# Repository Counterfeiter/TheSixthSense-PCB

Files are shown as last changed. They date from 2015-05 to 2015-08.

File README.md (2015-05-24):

TheSixthSense Schematic and PCB Files
==============

License
--------------
OSH - GPLv2

Software
--------------
Free Version of CADSoft Eagle v6 (.1)

Included
--------------
- versions history
- schematic
- PCB design
- Images

Schematic:
--------------
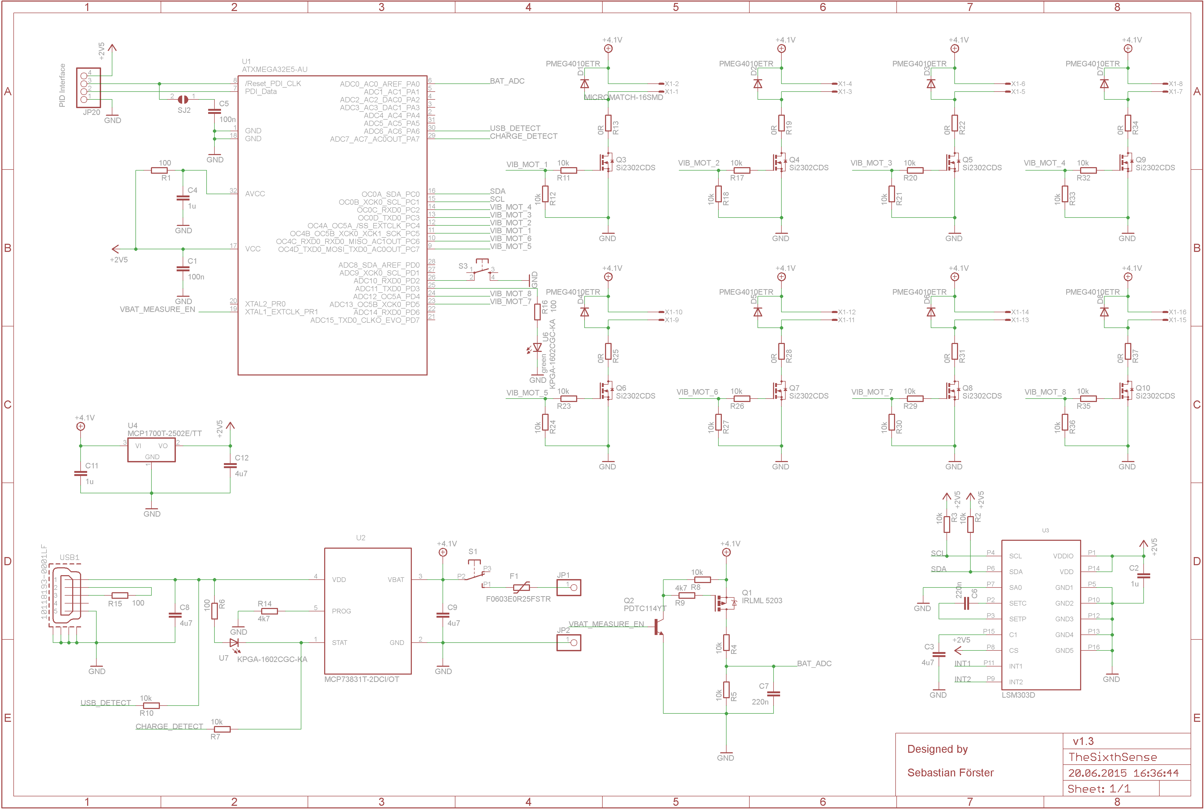
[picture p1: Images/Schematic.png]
Schematic


Board design:
--------------
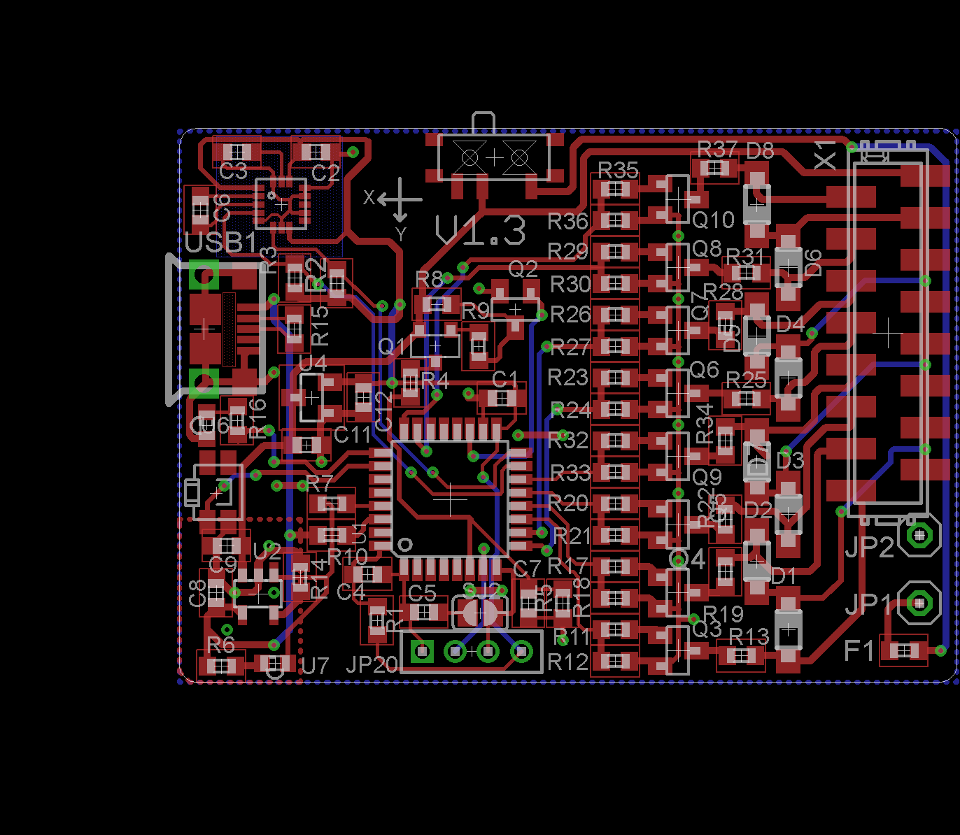
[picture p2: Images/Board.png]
Board


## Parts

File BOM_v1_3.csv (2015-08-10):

TheSixthSense v1.3 BOM; date 10.08.2015
Quantity | Value | Mouser Part Number | Device | Part
1 | 10-XX | 688-SKSCLAE010 | 10-XX | S3
2 | PINHD-1X1 | 538-22-28-8020 | PINHD-1X1 | JP1, JP2
8 | 0R | 667-ERJ-3GEY0R00V | R-EU_R0603 | R13, R19, R22, R25, R28, R31, R34, R37
3 | 1u | 80-C0603C105K8P | C-EUC0603 | C2, C4, C11
2 | 4k7 | 667-ERJ-3EKF4701V | R-EU_R0603 | R9, R14
4 | 4u7 | 80-C0603C475K8P | C-EUC0603 | C3, C8, C9, C12
23 | 10k | 667-ERJ-3EKF1002V | R-EU_R0603 | R2, R3, R4, R5, R7, R8, R10, R11, R12, R17, R18, R20, R21, R23, R24, R26, R27, R29, R30, R32, R33, R35, R36
4 | 100R | 667-ERJ-3EKF1000V | R-EU_R0603 | R1, R6, R15, R16
2 | 100n | 80-C0603C104K4R | C-EUC0603 | C1, C5
2 | 220n | 80-C0603X224K4R | C-EUC0603 | C6, C7
1 | 10118193-0001LF | 649-10118193-0001LF | MOLEX-47346-0001 | USB1
1 | ALPSSSSS811101 | 688-SSSS811101 | ALPSSSSS811101 | S1
1 | ATXMEGA32E5-AU | 556-ATXMEGA32E5-AU | AVR_XMEGA_E | U1
1 | F0603E0R25FSTR | 581-F0603E0R25FSTR | PMS1812 | F1
1 | IRLML 5203 | 942-IRLML5203TRPBF | IRLML5203 | Q1
2 | KPGA-1602CGC-KA | 859-LTST-S270KGKT | APA1606SURCK | U6, U7
1 | LSM303D | 511-LSM303DTR | LSM303D | U3
1 | MCP1700T-2502E/TT | 579-MCP1700T2502E/TT | XC6206P332MR | U4
1 | MCP73831 | 579-MCP73831T-2ATIOT | MCP73831 | U2
1 | MICROMATCH-16SMD | 571-8-2178711-6 | MICROMATCH-16SMD | X1
1 | PDTC114YT | 771-PDTC114YTT/R | BC848ALT1SMD | Q2
8 | PMEG4010ETR | 771-PMEG4010ETR115 | MBR0520LT | D1, D2, D3, D4, D5, D6, D7, D8
8 | Si2302CDS | 781-SI2302CDS-E3 | BSS123 | Q3, Q4, Q5, Q6, Q7, Q8, Q9, Q10
1 | MICROMATCH-16SMD-Plug | 571-8-215083-6

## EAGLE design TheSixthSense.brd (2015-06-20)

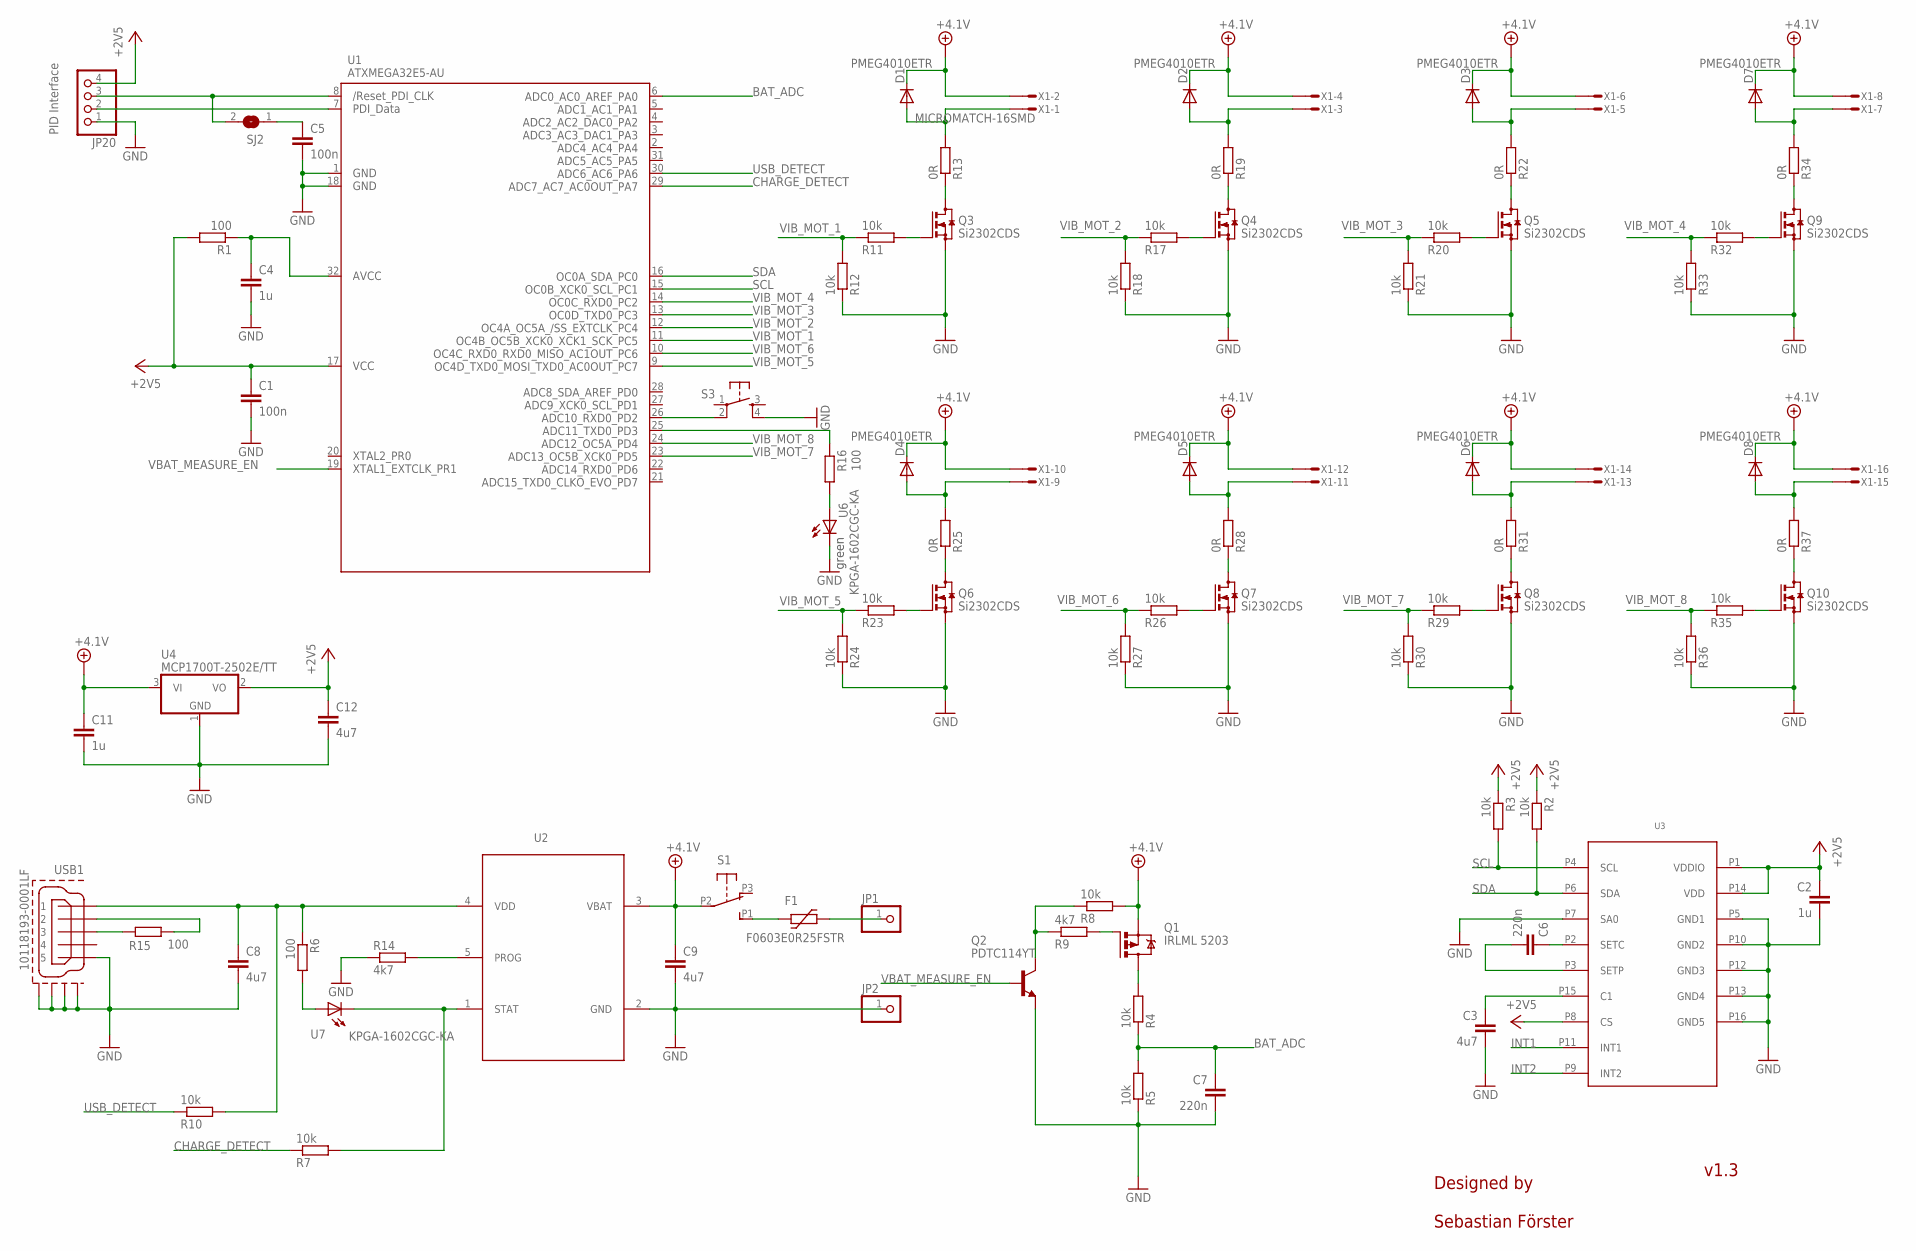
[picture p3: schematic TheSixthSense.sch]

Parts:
C1, C5: 100n; C0603
C2, C4, C11: 1u; C0603
C3, C8, C9, C12: 4u7; C0603
C6, C7: 220n; C0603
D1, D2, D3, D4, D5, D6, D7, D8: PMEG4010ETR; SOD123
F1: F0603E0R25FSTR; R0603
JP1, JP2: PINHD-1X1; 1X01
JP20: PINHD-1X4_2.00; 1X04M
Q1: IRLML 5203; MICRO3
Q2: PDTC114YT; SOT23
Q3, Q4, Q5, Q6, Q7, Q8, Q9, Q10: Si2302CDS; SOT23
R1, R6, R15, R16: 100; R0603
R2, R3, R4, R5, R7, R8, R10, R11, R12, R17, R18, R20, R21, R23, R24, R26, R27, R29, R30, R32, R33, R35, R36: 10k; R0603
R9, R14: 4k7; R0603
R13, R19, R22, R25, R28, R31, R34, R37: 0R; R0603
S1: ALPSSSSS811101; SSSS811101
S3: 10-XX; SKSCLAE010
SJ2: SJ
U1: ATXMEGA32E5-AU; TQFP32-08
U2: MCP73831; SOT23-5L
U3: LSM303D; LGA3X3_16L
U4: MCP1700T-2502E/TT; SOT23
U6, U7: KPGA-1602CGC-KA; CHIP-LED0603
USB1: 10118193-0001LF; MOLEX-47364-0001
X1: MICROMATCH-16SMD

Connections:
+3V3: C1.1, C2.1, C12.1, JP20.4, R1.2, R2.1, R3.1, U1.17 (VCC3), U3.P1 (VDDIO), U3.P8 (CS), U3.P14 (VDD), U4.2 (VO)
+4.1V: C9.1, C11.1, D1.C, D2.C, D3.C, D4.C, D5.C, D6.C, D7.C, D8.C, Q1.2 (S), R8.2, S1.P2, U2.3 (VBAT), U4.3 (VI), X1.1, X1.3, X1.5, X1.7, X1.9, X1.11, X1.13, X1.15
BAT_ADC: C7.1, R4.1, R5.2, U1.6 (PA0)
CHARGE_DETECT: R7.1, U1.29 (PA7)
GND: C1.2, C2.2, C3.2, C4.2, C5.2, C7.2, C8.2, C9.2, C11.2, C12.2, JP2.1, JP20.1, Q2.2 (E), Q3.2 (S), Q4.2 (S), Q5.2 (S), Q6.2 (S), Q7.2 (S), Q8.2 (S), Q9.2 (S), Q10.2 (S), R5.1, R12.1, R14.1, R18.1, R21.1, R24.1, R27.1, R30.1, R33.1, R36.1, S3.4 (S1), U1.1 (GND1), U1.18 (GND2), U2.2 (GND), U3.P5 (GND1), U3.P7 (SA0), U3.P10 (GND2), U3.P12 (GND3), U3.P13 (GND4), U3.P16 (GND5), U4.1 (GND), U6.C, USB1.5, USB1.GND1, USB1.GND2, USB1.GND3, USB1.GND4
GPS_ENABLE: Q2.3 (C), R8.1, R9.1
INT1: U3.P11 (INT1)
INT2: U3.P9 (INT2)
unnamed: C6.2, U3.P3 (SETP)
unnamed: Q1.3 (D), R4.2
unnamed: C3.1, U3.P15 (C1)
unnamed: C6.1, U3.P2 (SETC)
unnamed: F1.1, S1.P1 (S)
unnamed: R6.2, U7.A
unnamed: C8.1, R6.1, R10.2, U2.4 (VDD), USB1.1
unnamed: C5.1, SJ2.1
unnamed: C4.1, R1.1, U1.32 (AVCC)
unnamed: JP20.3, SJ2.2, U1.8 (RESET)
unnamed: JP20.2, U1.7 (PDI_DATA)
unnamed: R14.2, U2.5 (PROG)
unnamed: R15.1, USB1.3
unnamed: Q1.1 (G), R9.2
unnamed: Q3.1 (G), R11.2
unnamed: Q3.3 (D), R13.1
unnamed: D1.A, R13.2, X1.16
unnamed: R15.2, USB1.2
unnamed: Q4.1 (G), R17.2
unnamed: Q4.3 (D), R19.1
unnamed: D2.A, R19.2, X1.14
unnamed: Q5.1 (G), R20.2
unnamed: Q5.3 (D), R22.1
unnamed: D3.A, R22.2, X1.12
unnamed: Q6.1 (G), R23.2
unnamed: R16.2, U6.A
unnamed: Q6.3 (D), R25.1
unnamed: D4.A, R25.2, X1.8
unnamed: Q7.1 (G), R26.2
unnamed: Q7.3 (D), R28.1
unnamed: D5.A, R28.2, X1.6
unnamed: Q8.1 (G), R29.2
unnamed: Q8.3 (D), R31.1
unnamed: D6.A, R31.2, X1.4
unnamed: F1.2, JP1.1
unnamed: S3.2 (P1), U1.26 (PD2)
unnamed: R16.1, U1.25 (PD3)
unnamed: Q9.1 (G), R32.2
unnamed: Q9.3 (D), R34.1
unnamed: D7.A, R34.2, X1.10
unnamed: Q10.1 (G), R35.2
unnamed: Q10.3 (D), R37.1
unnamed: D8.A, R37.2, X1.2
NNNN: R7.2, U2.1 (STAT), U7.C
SCL: R3.2, U1.15 (PC1), U3.P4 (SCL)
SDA: R2.2, U1.16 (PC0), U3.P6 (SDA)
USB_DETECT: R10.1, U1.30 (PA6)
VBAT_MEASURE_EN: Q2.1 (B), U1.19 (PR1)
VIB_MOT_1: R11.1, R12.2, U1.11 (PC5)
VIB_MOT_2: R17.1, R18.2, U1.12 (PC4)
VIB_MOT_3: R20.1, R21.2, U1.13 (PC3)
VIB_MOT_4: R32.1, R33.2, U1.14 (PC2)
VIB_MOT_5: R23.1, R24.2, U1.9 (PC7)
VIB_MOT_6: R26.1, R27.2, U1.10 (PC6)
VIB_MOT_7: R29.1, R30.2, U1.23 (PD5)
VIB_MOT_8: R35.1, R36.2, U1.24 (PD4)

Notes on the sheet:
PID Interface
Designed by
Sebastian Förster
green
v1.3

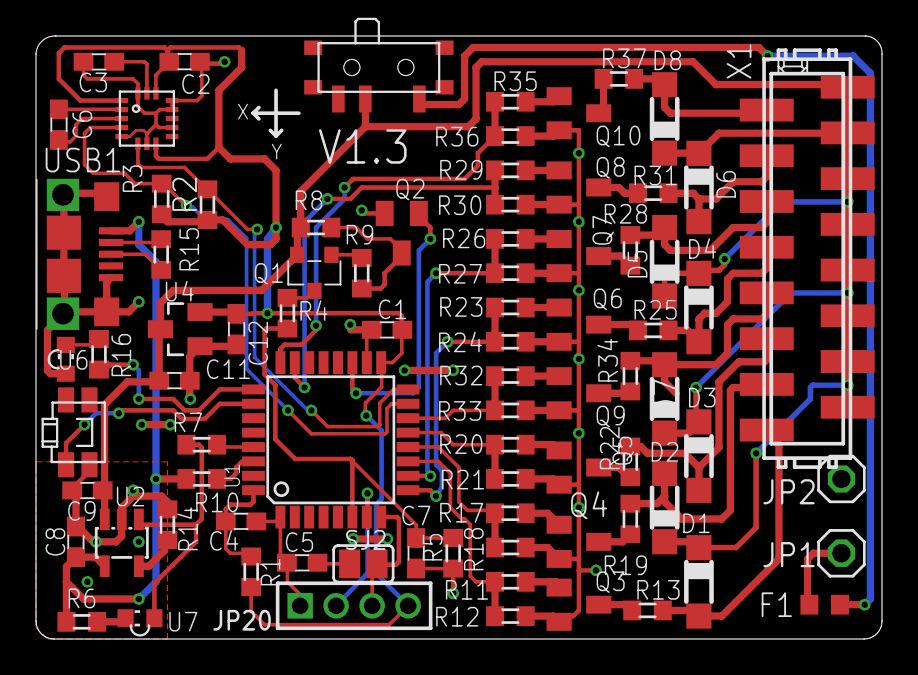
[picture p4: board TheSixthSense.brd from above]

Board: 2 copper layers, 47.0 x 33.5 mm, 81 parts (0 on the bottom side), 62 nets.

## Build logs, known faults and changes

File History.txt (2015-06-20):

History
--------
V1.0
-inital Board

V1.1
- Motor FET 5 & 6 nicht verbunden
- I2C Master an Port C gewechselt. Port D nur I2c Slave!

V1.2
- zwei weitere Mosfets an µC angeschlossen (Motor 5+6)
- besser ground plane

V1.3
- Hauptschalter hinzugefügt (300 mA max)
- Sicherung hinzugefügt (250 mA)
- Micro Match SMD Steckverbinder verwendet
- LIPO Ladestrom auf ca. 250 mA angepasst
- kleinen Taster hinzugefügt

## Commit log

2015-04-28 init commit
    [TheSixthSense.brd, TheSixthSense.sch]
2015-06-09 New 8 motor support! - adding motor 5&6: µC <-> Mosfets
    [TheSixthSense.brd, TheSixthSense.sch]
2015-06-20 - new version v1.3 - add a push button - add a fuse - add a switch to disconnect the battery - add a new motor connector
    [TheSixthSense.brd, TheSixthSense.sch]
2015-08-10 - new mouser part list for pcb v1.3
    [BOM_v1_3.csv]
